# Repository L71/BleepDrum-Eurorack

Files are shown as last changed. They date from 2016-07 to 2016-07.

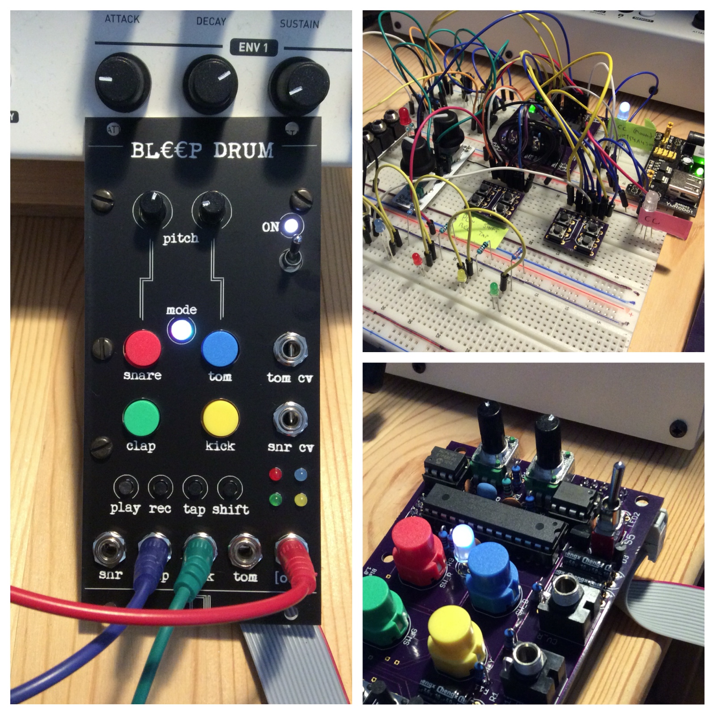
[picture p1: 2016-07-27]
HowItLooks.jpg

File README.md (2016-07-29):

Bleep Drum Eurorack
===================

This is the Bleep Drum by Bleep Labs (www.bleeplabs.com) converted to a Eurorack module.

It is a pretty basic adaptation with trigger and CV inputs added to make external control possible in addition to the original pad buttons and pitch knobs.

* Similar output circuitry as original, directly from DAC, 5V P-P (which is a bit lower than common in Eurorack)
* Trigger inputs are eurorack voltage compatible (positive edge trig, >1V)
* Input CVs are averaged together with knob values when plugged in (0-5V internally)  
* Power switch so it can be rebooted into noise mode independently of rack 
* The PCB layout for the RGB LED I used is wrong so the colors don't line up with the Bleep drum manual, but I don't care :) Also, this has little impact when it is just used as sound module.
* additional blinkenlights =) 

The original files and source code from Bleep Labs can be found here: https://github.com/BleepLabs/Bleep-Drum 

This module is working with the Bleep Drum MIDI firmware v12. Original Bleep Drum programmed chips should also work (but has not been tested).  

The internal drum sequencing in the module works I think - I have no original Bleep Drum to compare with - but I can't seem to get it to record or play back anything at all when the circuit sits on a breadboard (this is also why a clock output is missing).
It works fine as a sound source which was the main reason I did this anyway so I'll leave it like this. Also, the C&K switches used for the drum pads turn out to be pretty bad for playing anyway.

Panel notes: I ordered the panel from Ponoko, laser cut and engraved on 1.5mm acrylic, black surface on white core. This gives a quite nice panel, black with engraved white text on it. Not exactly bullet proof but solid enought when the PCB is attached with all jacks and additional support screws. The jacks will hold the panel 10mm above the PCB so use matching 10mm spacer bolts. 
Using a thicker panel (>2mm) is not recommended since the jack nuts will no longer fit properly.  

The module has a standard 10pin Eurorack +/- 12V power connector but it only uses the +12V and should run just fine on any DC power source that provides at least 7-8 volts if used standalone.  

Please note
===========
...that this module was developed entirely without any involvement from Bleep Labs. Whatever may be wrong with it is entirely my doing. Bleep Labs cannot be expected to answer questions about this module or anything related to it. 

The schematics, the PCB and the panel are all licensed cc-by-sa (Creative Commons Attribution-ShareAlike) 4.0.

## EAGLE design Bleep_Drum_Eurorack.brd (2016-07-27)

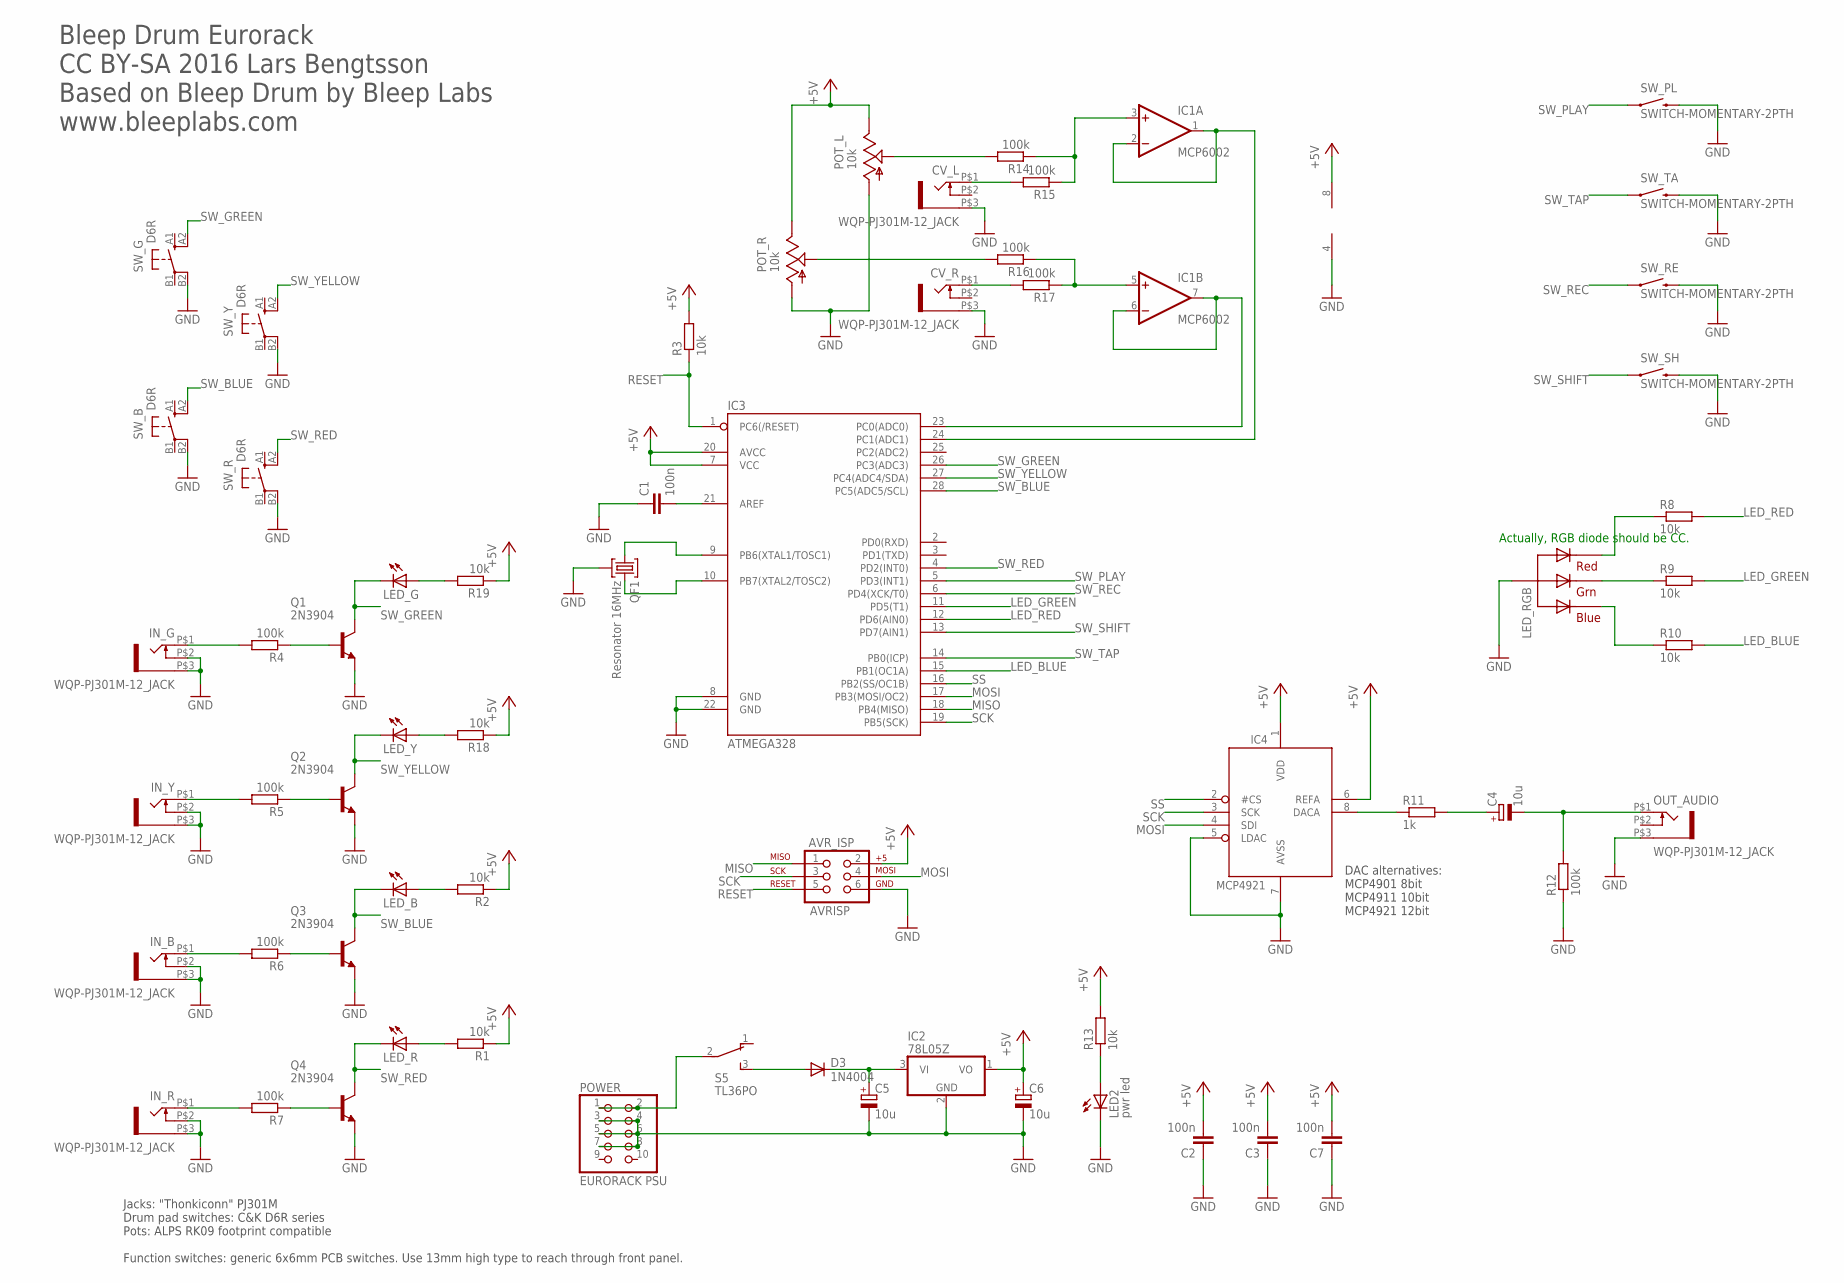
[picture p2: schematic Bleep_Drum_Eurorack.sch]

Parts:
AVR_ISP: AVRISP; 2X3
C1, C2, C3, C7: 100n; C025-025X050
C4, C5, C6: 10u; E2,5-5
CV_L: WQP-PJ301M-12_JACK
CV_R: WQP-PJ301M-12_JACK
D3: 1N4004; D-2.5
IC1: MCP6002; DIL08
IC2: 78L05Z; TO92
IC3: ATMEGA328; DIL28-3
IC4: MCP4921; DIL08
IN_B: WQP-PJ301M-12_JACK
IN_G: WQP-PJ301M-12_JACK
IN_R: WQP-PJ301M-12_JACK
IN_Y: WQP-PJ301M-12_JACK
LED2: pwr led; LED3MM
LED_B: LED3MM
LED_G: LED3MM
LED_R: LED3MM
LED_RGB: RGBLED_CA-5MM; LED5MMRGB
LED_Y: LED3MM
OUT_AUDIO: WQP-PJ301M-12_JACK
POT_L: 10k; ALPS_POT_VERTICAL
POT_R: 10k; ALPS_POT_VERTICAL
POWER: EURORACK PSU; 2X05
Q1, Q2, Q3, Q4: 2N3904; TO92
QF1: Resonator 16MHz; UM1
R1, R2, R3, R8, R9, R10, R13, R18, R19: 10k; 0204V
R4, R5, R6, R7, R12, R14, R15, R16, R17: 100k; 0204V
R11: 1k; 0204V
S5: TL36PO; TL3XPO
SW_B: D6R
SW_G: D6R
SW_PL: SWITCH-MOMENTARY-2PTH; TACTILE-PTH
SW_R: D6R
SW_RE: SWITCH-MOMENTARY-2PTH; TACTILE-PTH
SW_SH: SWITCH-MOMENTARY-2PTH; TACTILE-PTH
SW_TA: SWITCH-MOMENTARY-2PTH; TACTILE-PTH
SW_Y: D6R

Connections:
+5V: AVR_ISP.2, C2.2, C3.2, C6.+, C7.2, IC1.8 (V+), IC2.1 (VO), IC3.7 (VCC), IC3.20 (AVCC), IC4.1 (VDD), IC4.6 (REFA), POT_L.P$1 (E), POT_R.P$1 (E), R1.1, R2.1, R3.2, R13.2, R18.1, R19.1
+12V_IN: POWER.1, POWER.2, S5.2
GND: AVR_ISP.6, C1.1, C2.1, C3.1, C5.-, C6.-, C7.1, CV_L.P$3 (1), CV_R.P$3 (1), IC1.4 (V-), IC2.2 (GND), IC3.8 (GND), IC3.22 (GND), IC4.5 (LDAC), IC4.7 (AVSS), IN_B.P$2 (3), IN_B.P$3 (1), IN_G.P$2 (3), IN_G.P$3 (1), IN_R.P$2 (3), IN_R.P$3 (1), IN_Y.P$2 (3), IN_Y.P$3 (1), LED2.K (C), LED_RGB.2 (VCC), OUT_AUDIO.P$3 (1), POT_L.P$3 (A), POT_R.P$3 (A), POWER.3, POWER.4, POWER.5, POWER.6, POWER.7, POWER.8, Q1.3 (E), Q2.3 (E), Q3.3 (E), Q4.3 (E), QF1.2, R12.1, SW_B.B2 (P1), SW_G.B2 (P1), SW_PL.3 (2), SW_R.B2 (P1), SW_RE.3 (2), SW_SH.3 (2), SW_TA.3 (2), SW_Y.B2 (P1)
LED_BLUE: IC3.15 (PB1(OC1A)), R10.2
LED_GREEN: IC3.11 (PD5(T1)), R9.2
LED_RED: IC3.12 (PD6(AIN0)), R8.2
MISO: AVR_ISP.1, IC3.18 (PB4(MISO))
MOSI: AVR_ISP.4, IC3.17 (PB3(MOSI/OC2)), IC4.4 (SDI)
unnamed: C4.+, R11.2
unnamed: IC4.8 (DACA), R11.1
unnamed: C4.-, OUT_AUDIO.P$1 (2), R12.2
unnamed: C5.+, D3.C, IC2.3 (VI)
unnamed: IC3.9 (PB6(XTAL1/TOSC1)), QF1.1
unnamed: IC3.10 (PB7(XTAL2/TOSC2)), QF1.3
unnamed: LED_RGB.1 (RED), R8.1
unnamed: C1.2, IC3.21 (AREF)
unnamed: IN_Y.P$1 (2), R5.2
unnamed: Q2.2 (B), R5.1
unnamed: LED_R.A, R1.2
unnamed: IC1.1 (OUT), IC1.2 (-IN), IC3.24 (PC1(ADC1))
unnamed: LED_RGB.3 (GREEN), R9.1
unnamed: Q1.2 (B), R4.1
unnamed: IN_G.P$1 (2), R4.2
unnamed: LED_RGB.4 (BLUE), R10.1
unnamed: D3.A, S5.3 (S)
unnamed: Q3.2 (B), R6.1
unnamed: IN_B.P$1 (2), R6.2
unnamed: IN_R.P$1 (2), R7.2
unnamed: Q4.2 (B), R7.1
unnamed: LED2.A, R13.1
unnamed: LED_B.A, R2.2
unnamed: LED_Y.A, R18.2
unnamed: LED_G.A, R19.2
unnamed: POT_L.P$2 (S), R14.2
unnamed: IC1.3 (+IN), R14.1, R15.1
unnamed: CV_L.P$1 (2), R15.2
unnamed: POT_R.P$2 (S), R16.2
unnamed: IC1.5 (+IN), R16.1, R17.1
unnamed: CV_R.P$1 (2), R17.2
unnamed: IC1.6 (-IN), IC1.7 (OUT), IC3.23 (PC0(ADC0))
RESET: AVR_ISP.5, IC3.1 (PC6(/RESET)), R3.1
SCK: AVR_ISP.3, IC3.19 (PB5(SCK)), IC4.3 (SCK)
SS: IC3.16 (PB2(SS/OC1B)), IC4.2 (#CS)
SW_BLUE: IC3.28 (PC5(ADC5/SCL)), LED_B.K (C), Q3.1 (C), SW_B.A2 (S1)
SW_GREEN: IC3.26 (PC3(ADC3)), LED_G.K (C), Q1.1 (C), SW_G.A2 (S1)
SW_PLAY: IC3.5 (PD3(INT1)), SW_PL.1
SW_REC: IC3.6 (PD4(XCK/T0)), SW_RE.1
SW_RED: IC3.4 (PD2(INT0)), LED_R.K (C), Q4.1 (C), SW_R.A2 (S1)
SW_SHIFT: IC3.13 (PD7(AIN1)), SW_SH.1
SW_TAP: IC3.14 (PB0(ICP)), SW_TA.1
SW_YELLOW: IC3.27 (PC4(ADC4/SDA)), LED_Y.K (C), Q2.1 (C), SW_Y.A2 (S1)

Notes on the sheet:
Actually, RGB diode should be CC.
Jacks: "Thonkiconn" PJ301M Drum pad switches: C&K D6R series Pots: ALPS RK09 footprint compatible Function switches: generic 6x6mm PCB switches. Use 13mm high type to reach through front panel.
Bleep Drum Eurorack CC BY-SA 2016 Lars Bengtsson Based on Bleep Drum by Bleep Labs www.bleeplabs.com
DAC alternatives: MCP4901 8bit MCP4911 10bit MCP4921 12bit

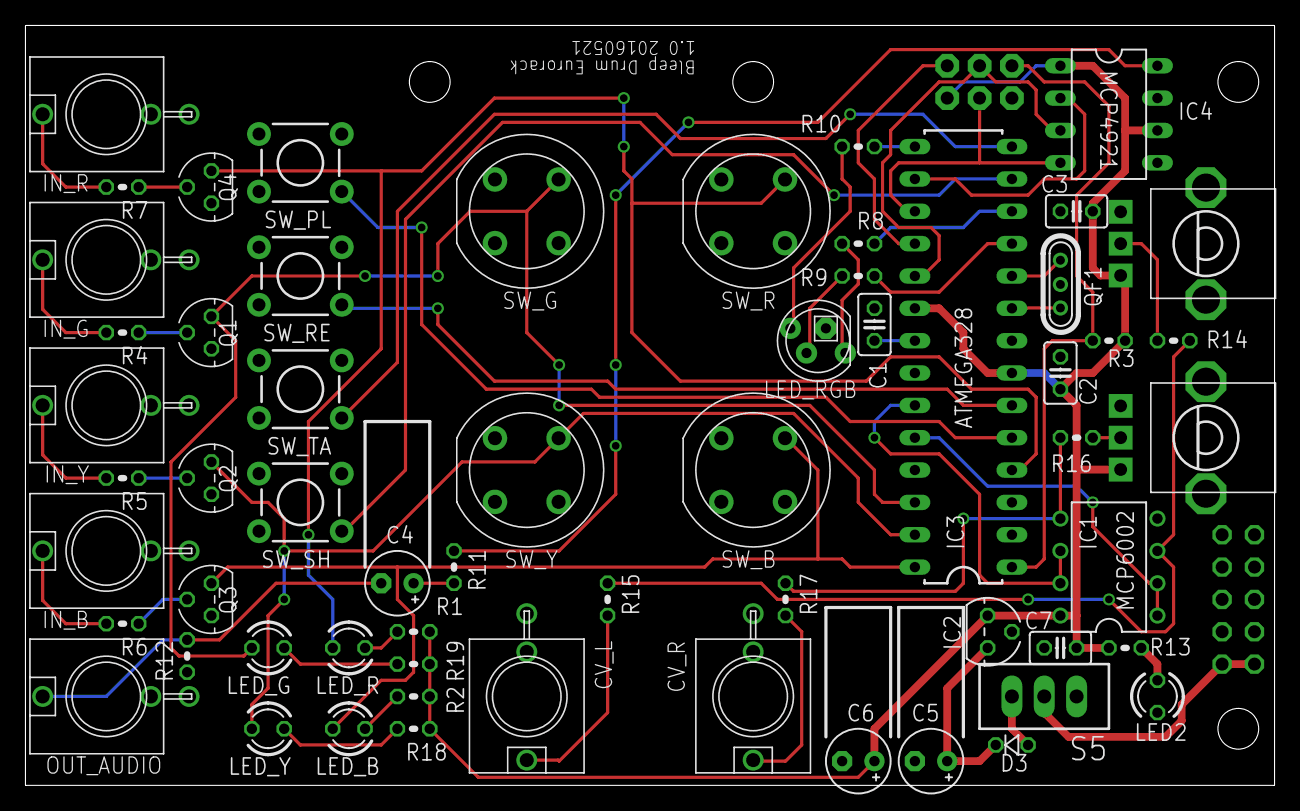
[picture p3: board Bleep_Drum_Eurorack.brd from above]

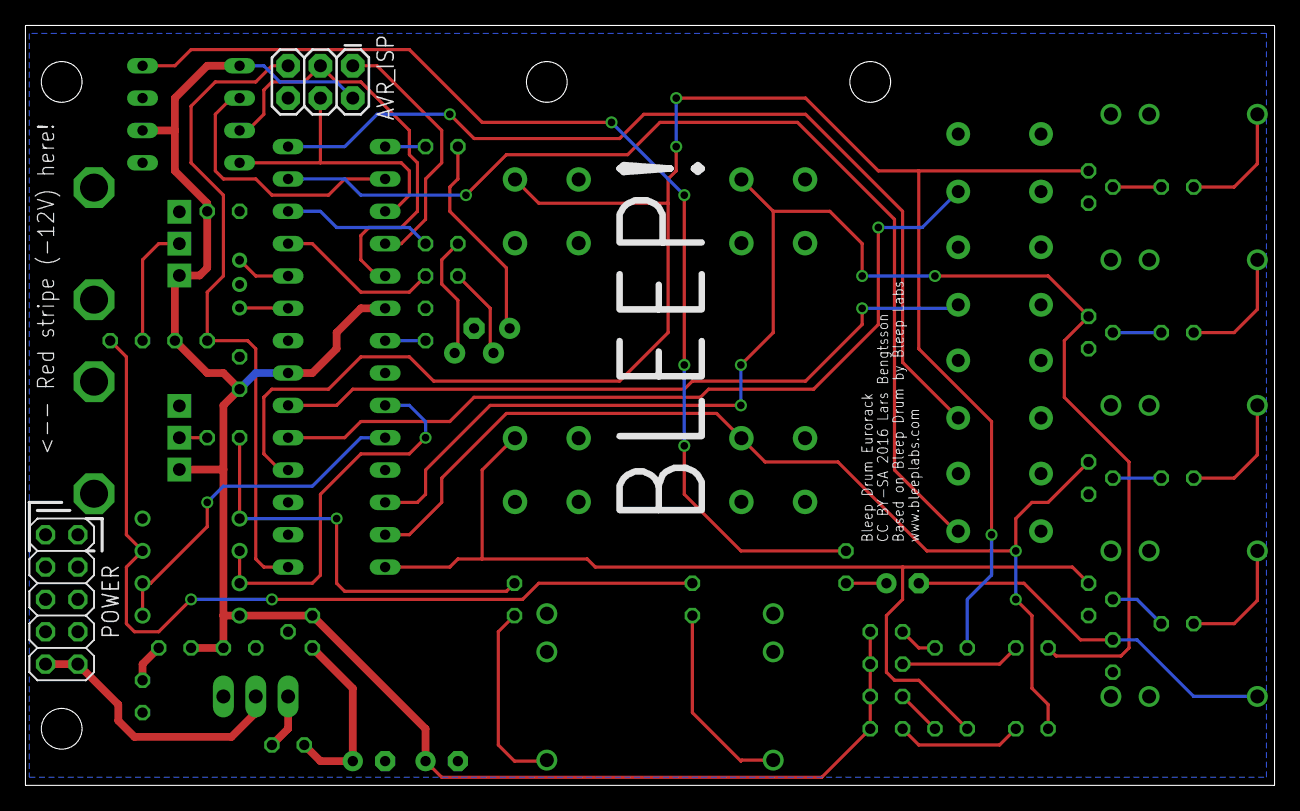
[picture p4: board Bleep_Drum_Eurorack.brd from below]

Board: 2 copper layers, 98.1 x 59.7 mm, 62 parts (2 on the bottom side), 51 nets.

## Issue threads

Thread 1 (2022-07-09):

clarification on the current state of the module

KeLaiFu, 2022-07-09:
First of all, thanks for sharing your work, my rack is currently sporting 2 of your MS20 modules.

Apologies if I am missing the obvious, but in the readme it states:
'The internal drum sequencing in the module works I think - I have no original Bleep Drum to compare with - but I can't seem to get it to record or play back anything at all when the circuit sits on a breadboard (this is also why a clock output is missing). It works fine as a sound source...'

Does this mean the final PCBs also have issues recording and playing back, or it was something you experienced while breadboarding?

I would like to build this myself and I am not concerned about the internal recoding functions anyway, but if the record controls arent usuable, I will remove them from the design.

Thanks again

BleepLabs, 2022-07-11:
Hello. I'm not involved with this project at all but most probably there's an issue with pin assignments as I've changed those a few times over the years. What version of the code is this hardware intended for? Looking at the schematics it doesn't line up with the current version. That would explain why recording isn't working.

KeLaiFu, 2022-07-14:
> Hi! @KeLaiFu Cool! Happy to hear that! =) Re: the bleep drum module, if I remember correctly sequence recording actually works on the finished module but I have never used it like that for more than a few minutes so the play/record functions may well be a bit broken without me realising it. I have no modular things connected at the moment so I can't check it.
>

That's fine for me, I thought about this module over the last few days and decided I wanted to make it look somewhat like a large version of the original, with illuminated arcade style buttons dominating the panel, and omitting the record functions anyway, so as long as it can be triggered via jacks and buttons, I am good.  Thanks for the feedback

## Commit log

2016-05-22 Initial commit of (almost) finished files.
    [Bleep_Drum_Eurorack.brd, Bleep_Drum_Eurorack.sch]
2016-05-22 Updated info text a bit.
    [Bleep_Drum_Eurorack.sch]
2016-06-19 Moved R11 a bit. Moved a few component labels.
    [Bleep_Drum_Eurorack.brd]
2016-07-27 Changed ATmega328P into ATmega328. Arduino environment seems to expect the latter type (both work fine when programmed. It's just hard to get there with a "P" type chip :) ).
    [Bleep_Drum_Eurorack.brd, Bleep_Drum_Eurorack.sch]
2016-07-27 Added note about switches.
2016-08-08 Updated with the panel version that I actually used when ordering prototypes... (oops! :))

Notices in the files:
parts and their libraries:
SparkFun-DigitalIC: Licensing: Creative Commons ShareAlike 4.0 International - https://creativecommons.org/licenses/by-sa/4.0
